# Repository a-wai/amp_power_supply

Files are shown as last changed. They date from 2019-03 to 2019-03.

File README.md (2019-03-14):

# Amplifier power supply

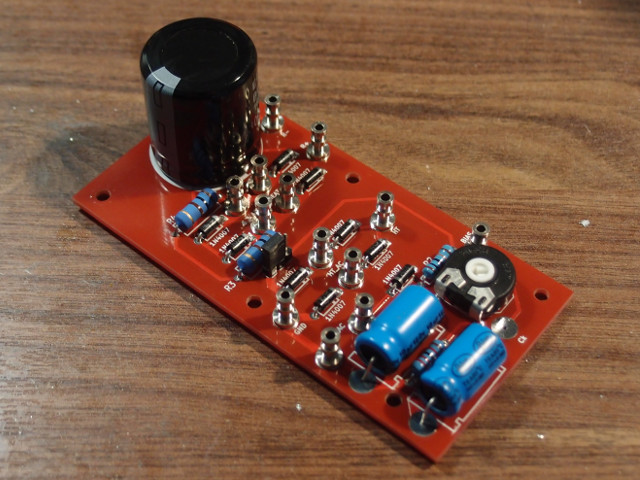
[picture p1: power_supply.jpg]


A generic power supply PCB for tube amplifiers, suitable for both fixed bias
and cathode bias amplifiers.

### Copyright

Copyright 2019, Arnaud Ferraris.

This documentation describes Open Hardware and is licensed under the
CERN OHL v.1.2.

You may redistribute and modify this documentation under the terms of the
[CERN OHL v.1.2](http://ohwr.org/cernohl). This documentation is distributed
WITHOUT ANY EXPRESS OR IMPLIED WARRANTY, INCLUDING OF MERCHANTABILITY,
SATISFACTORY QUALITY AND FITNESS FOR A PARTICULAR PURPOSE.

Please see the CERN OHL v.1.2 for applicable conditions.

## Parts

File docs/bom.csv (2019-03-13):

Fixed bias
Component | Description | References | Value | Quantity Per PCB | MFR | MPN | SPR | SPN
1 | Polarized capacitor | C3 | 10000µ/16V | 1 | Epcos | B41303J4109M | RS | 208-7122
2 | Polarized capacitor | C1-C2 | 10µ/160V | 2 | RS Pro |  | RS | 707-6401
3 | Diode | D1-D9 | 1N4007 | 9 |  |  | Tube Town | 1n4007
5 | Turret Type 32 | P1-P13 |  | 13 |  |  | Tube Town | tur-tt32-25
8 | Resistor | R1 | 22K | 1 | Xicon | 273-22K-RC | Tube Town | rxi-22k
6 | Resistor | R2 | 100K | 1 | Xicon | 273-100K-RC | Tube Town | rxi-100k
7 | Resistor | R3-R4 | 100R/2W | 2 | Vitrohm | PO593-0-5-100 | Tube Town | rmo-100-2
9 | Potentiometer | RV1 | 10K | 1 | Piher | PT15 | Tube Town | rpo-10k
Cathode bias
Component | Description | References | Value | Quantity Per PCB | MFR | MPN | SPR | SPN
1 | Polarized capacitor | C3 | 10000µ/16V | 1 | Epcos | B41303J4109M | RS | 208-7122
2 | Polarized capacitor | Ck | 220µ/63V | 1 |  |  | Tube Town | cax-220-63
3 | Diode | D1-D8 | 1N4007 | 8 |  |  | Tube Town | 1n4007
4 | Turret Type 32 | P1-P13 +3* |  | 16 |  |  | Tube Town | tur-tt32-25
5 | Resistor | R3-R4 | 100R/2W | 2 | Vitrohm | PO593-0-5-100 | Tube Town | rmo-100-2
6 | Resistor | Rk | * | 1
Notes: | C3 P8 P13 & D5-D8 are optional (use only if you need a 6V DC relays PSU)
 | For cathode bias operation drill C1 & C2 '+' pads to 2.8mm and place turrets there
 | Place Rk (value dependent on your amp) between C1 '+' pad & 'BIAS' turret
 | Place turret on 'Ck' pad
 | Place Ck between C2 '+' pad & 'Ck' turret

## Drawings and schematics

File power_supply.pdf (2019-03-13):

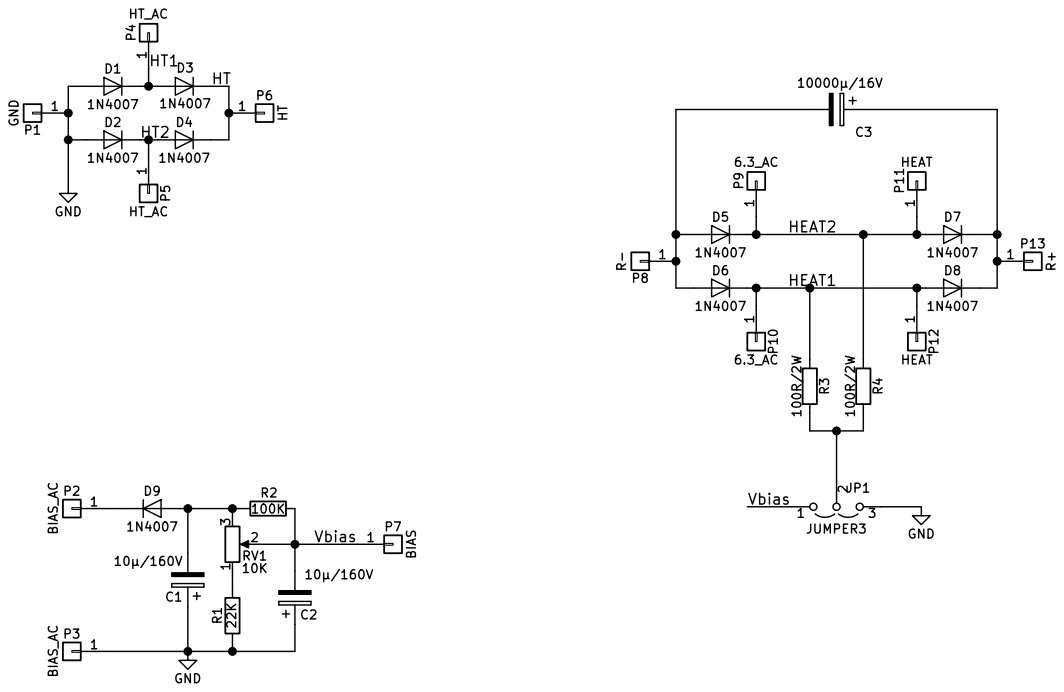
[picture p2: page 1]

Id: 1/1 Title: Amplifier PSU

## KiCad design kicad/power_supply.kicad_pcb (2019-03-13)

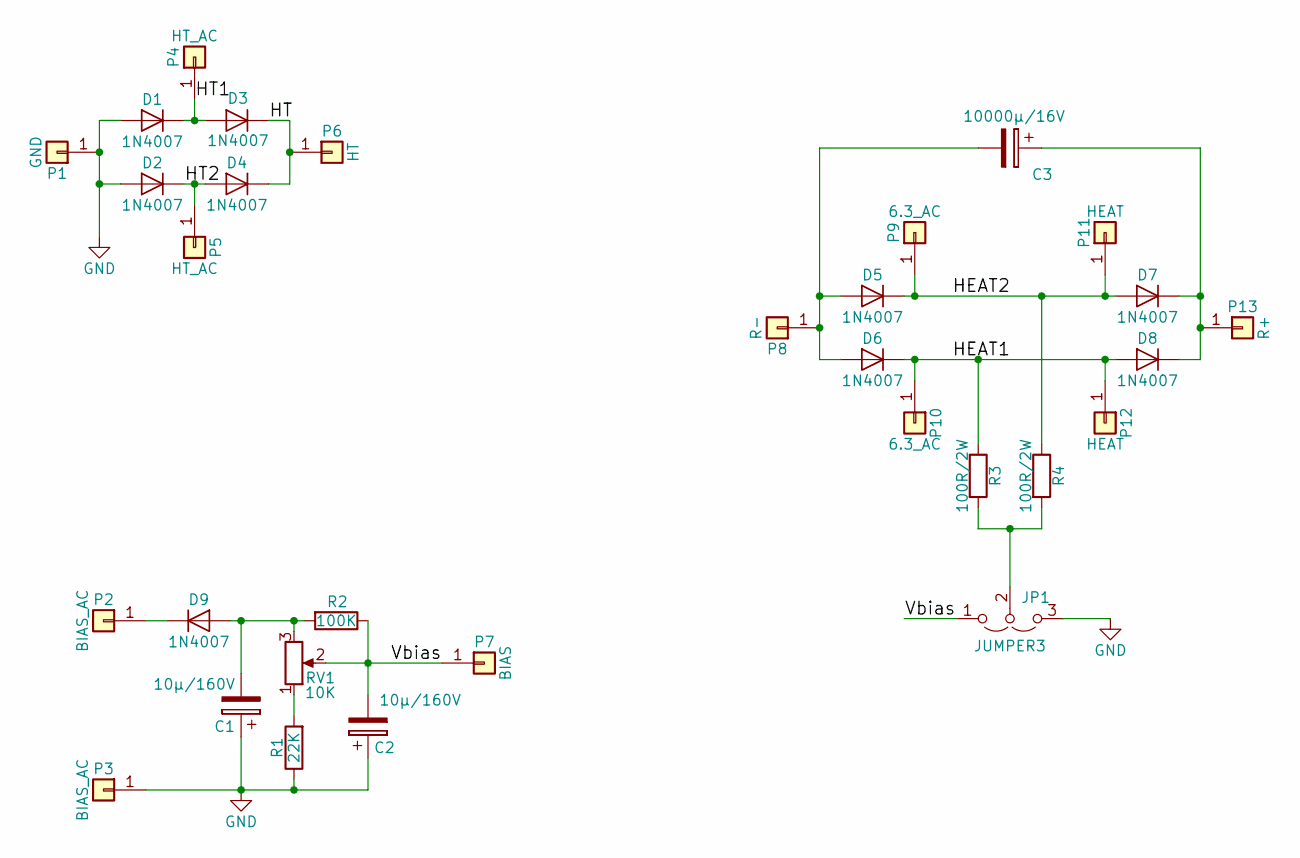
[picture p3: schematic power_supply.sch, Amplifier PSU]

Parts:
C1, C2: 10µ/160V; CP_Axial_L18.0mm_D10.0mm_P25.00mm_Horizontal
C3: 10000µ/16V; CP_Radial_D26.0mm_P10.00mm_SnapIn; MPN B41303J4109M
D1, D2, D3, D4, D5, D6, D7, D8, D9: 1N4007; D_DO-41_SOD81_P7.62mm_Horizontal
JP1: JUMPER3; PinHeader_1x03_P2.54mm_Vertical
P1: GND; TURRET
P2, P3: BIAS_AC; TURRET
P4, P5: HT_AC; TURRET
P6: HT; TURRET
P7: BIAS; TURRET
P8: R-; TURRET
P9, P10: 6.3_AC; TURRET
P11, P12: HEAT; TURRET
P13: R+; TURRET
R1: 22K; R_Axial_DIN0309_L9.0mm_D3.2mm_P12.70mm_Horizontal; MPN 273-22K-RC
R2: 100K; R_Axial_DIN0309_L9.0mm_D3.2mm_P12.70mm_Horizontal; MPN 273-100K-RC
R3, R4: 100R/2W; R_Axial_DIN0414_L11.9mm_D4.5mm_P15.24mm_Horizontal; MPN PO593-0-5-100
RV1: 10K; Potentiometer_Piher_PT-15-V02_Vertical; MPN PT15

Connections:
/HEAT1: D6.1 (K), D8.2 (A), P10.1, P12.1, R3.1
/HEAT2: D5.1 (K), D7.2 (A), P9.1, P11.1, R4.1
/HT: D3.1 (K), D4.1 (K), P6.1
/HT1: D1.1 (K), D3.2 (A), P4.1
/HT2: D2.1 (K), D4.2 (A), P5.1
/Vbias: C2.2, JP1.1 (A), P7.1, R2.1, RV1.2; also elsewhere on the board
GND: C1.1, C2.1, D1.2 (A), D2.2 (A), JP1.3 (B), P1.1, P3.1, R1.1
unnamed: C1.2, D9.2 (A), R2.2, RV1.3
unnamed: C3.1, D7.1 (K), D8.1 (K), P13.1
unnamed: C3.2, D5.2 (A), D6.2 (A), P8.1
unnamed: D9.1 (K), P2.1
unnamed: JP1.2 (C), R3.2, R4.2
unnamed: R1.2, RV1.1

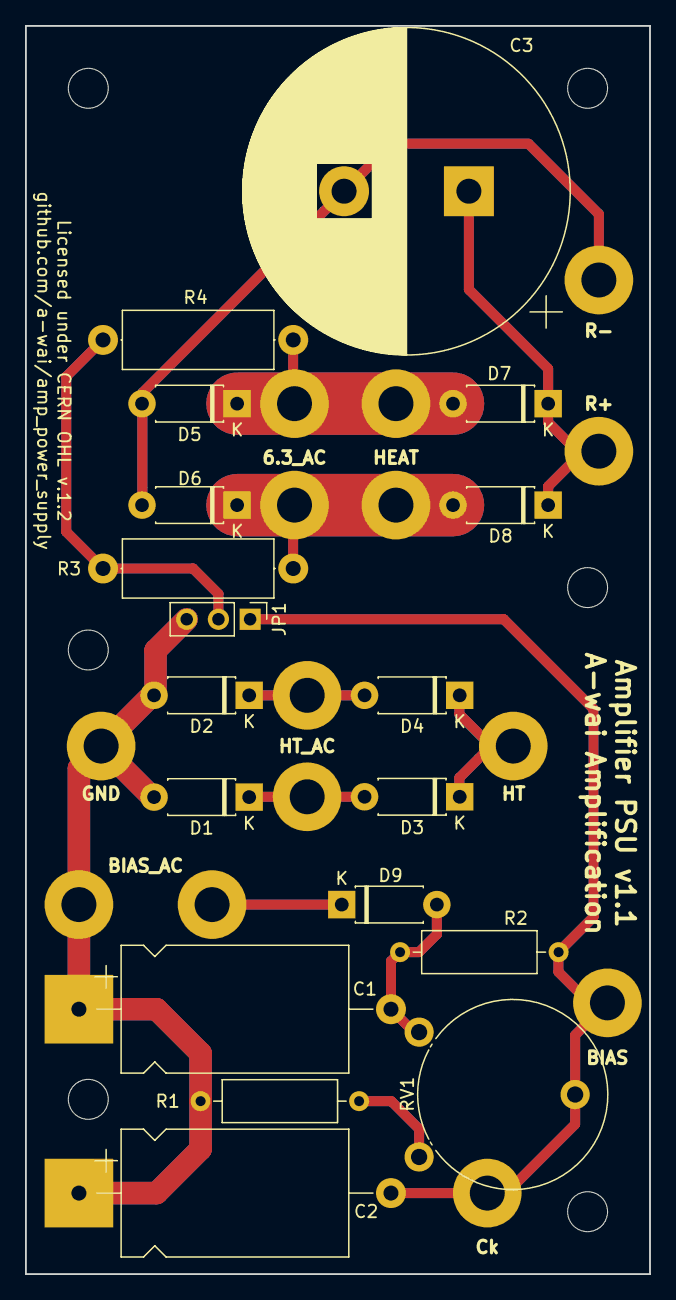
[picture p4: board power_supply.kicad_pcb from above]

Board: 2 copper layers, 50.0 x 100.0 mm, 32 parts (0 on the bottom side), 13 nets.

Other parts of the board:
T1: Ck; TURRET

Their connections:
/Vbias: T1.1; also elsewhere on the board

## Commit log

2016-08-25 Initial import
    [power_supply.kicad_pcb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]
2016-09-08 Update track widths & route on both layers
    [power_supply.drl, power_supply.gbl, power_supply.gbo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]
2016-11-09 Fix tracks near fixation hole & pot too close to bias turret
    [power_supply.kicad_pcb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]
2016-11-09 Regenerate drill file & add project name
    [power_supply.drl, power_supply.gbl, power_supply.gbo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]
2019-03-13 Update for KiCAD v5
    [power_supply.drl, power_supply.gbl, power_supply.gbo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]
2019-03-13 Move design files to a subfolder + add full license documentation
    [power_supply.kicad_pcb, power_supply.sch]
2019-03-13 Add BOM + PDF schematics
    [bom.csv, power_supply.kicad_pcb, power_supply.sch]

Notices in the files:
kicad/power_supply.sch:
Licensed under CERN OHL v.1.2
